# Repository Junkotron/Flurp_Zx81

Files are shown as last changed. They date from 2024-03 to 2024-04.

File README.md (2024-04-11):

# "Flurp zx81" on an fpga lots of stuff borrowed from "Blackice MX ZX81"
# Now for use on the Olimex ice40 8k board.

Second release some cleanup done but some elephants still remain

Features so far of the "Flurp"

* 16k or 1k ZX81 running at 3.2MHz
* PAL/NTSC output
* mic/ear/line for playing and recording sound files
* PS/2 keyboard connector (works with most USB keyboards)
* A debug port for a logic analyzer
* Serial port can now fairly reliably quick load programs
* 5 volt in from mobile charger, USB or similar

"Flurp" PCB drawings in kicad all in 0.1" grid so "banana finger" is no excuse
anymore, all hole-mounted like in the old days. If you, like me, fiddled
together a Zeddy at twelve you should be able to do this. Actually it is 
easier since no nerve-wrecking 40 pinners need be pressed in their sockets.
Components as far as I know can still be obtained, caps, connectors,
resistors and a single diode for over-voltage from the cassette interface
(could be omitted for the brave at heart).

First PCB is "in the air" as of this writing.

Since there is so many ideas of the connectors I made them as simple
pin and hole headers so there is no on-board fittings for RCA-jacks, 3.5mm
keyboard or similar since the chance of you obtaining whatever I got hold
of would be near-zero, just dive into that junkbox you got and see what
pops up!
I assume anyone attempting this should know their way around old-timer
connectors or if you are younger, wikipedia and google for info
on antiques :)

ZX81 currently only with 1k or 16k config, one major improvement with the
Olimex board is its 512k SRAM which we can use as we like.
Most other boards have SDRAM and although this probably also can
be made working I leave it as an excercise to the experts.
Currently only 16k is used. Plans to move the ROM here as well, this
currently resides in the internal FPGA memory.

As when mentioning the ROM I sucessfully replaced the original ROM with
the infamous "ASZMIC" rom image and got the example from the manual
working (see aszmic.sh in speedloader/) 

There is also an example of where the virtual keyboard produces a really
long 10 REM ... line suitable for storing machine code, in the old days
this would make your thumb go numb since this old piece of antique did not
have key repeat..

A composite output, there is an unfortunate "panache" with a wobble
on the first text line, dont know if this is due to the almost-PAL nature
of the ZX81 or something introduced later on. I tried a modulator (VHF) 
of some cheap no-brand type which would actually feed an older flatscreen
I got. Seems the really new flat screens cannot do PAL/NTSC anymore.
Not tried on a real fat-TV or monitor yet.

An "ear" input, changes from Sinclair original is some pulldown I seemed
to need on the FPGA side and some cowardly added zener 3.3 volts since
the FPGA is not 5v tolerant like the original ULA.

A "line" output, this is to be fed into a line input of some kind of PC 
soundblaster, I used the "aplay/arecord" utilities on Linux to act as the
tape recorder, it actually worked more or less out of the box.
I also added a modified bandbass filter for the line level that aims
as "doing the same thing" as the original "mic" circuitry but with a higher
level.

A PS/2 keyboard input with some resistors again to adapt to the
3.3 volt logic. It also works on most USB keyboards I tried, forcing them
into legacy PS/2 mode with some pullups.
If you take the usb connector, the wires in the schematic should align with
how the physical usb port is layed out so you can start with the plus which
use to be red and then work your way into whatever connector you have available
You could also get a PS/2 keyboard on ebay though this more obvious option
has not been tested.

The 34-pole connector for the FPGA module (Olimex) note that the notch in
the FPGA boards connector should face the nearest rim of the pcb, there is a 
"Notch!" silk screen marker. I'm not in any way a professional cad:er so
I may have broken some standard ways of working concerning the connectors.
Possibly you will use a female 0.1" headers with no notch. I found that
adding a small dot of hot glue, let it cool off some and then press the
module on will "mold" a notch without clogging the fpga board with glue.
This "notch" has been quite useful for avoiding gray smoke.

A "mic" output, this is made according to the originals but has as of yet
not worked. I added a 5 volt feed in case someone wants to try to make some
analog adaptions to it, I tried to amplify the signal with a 741 but to
no avail. Have not tested with a "real" tape recorder will do that when I
get a hold of one and some tape.

Some games require you to have only 1k so there is a connector that will
downgrade the Flurp to 1k after a reset, otherwise poking RAMTOP should
work for most such games.

Another connector will pull the "pin 22" on the "ULA" high which should
give you NTSC format, this is untested so far. In the old days most
american TV-sets would eat the PAL signal just as well.

Loading old games, I have been successful in using the "zx81putil" for
converting the p-file games available into wav files and then playing them
via the line-out of my PC sound blaster into the "ear" of the Flurp

.. Below here is some cool stuff that is not really necessary
.. these connectors can be omitted

A connector for a six-pin serial module which is popular with Arduinos
and similar. Now the speedloader is working and also you can "remote
type" on the ZX81 keyboard.

The olimex 32u4 or similar is used for programming the SPI flash of the
FPGA, we sometimes need to reset the FPGA, this can be done with the
reset button on the olimex ice40 board itself or with for instance
> sudo iceprogduino -t
Which reads the flash ID (but also does a full reset much faster than a full
 reprogram)

Speedloader can now both produce load files and fast load them
Check out "speedloader.txt" for more info

A way to run the ZX keyboard from this serial port is now implemented
the speeloader/keysend.c can be used to primitively execute commands
on the flurp, such as 'RUN' 'LOAD ""' 'NEW' etc.

A 10-pin connector for a Logic Probe, dirt cheap and really useful if you
want to dive into the FPGA firmware.

Thats all for now!

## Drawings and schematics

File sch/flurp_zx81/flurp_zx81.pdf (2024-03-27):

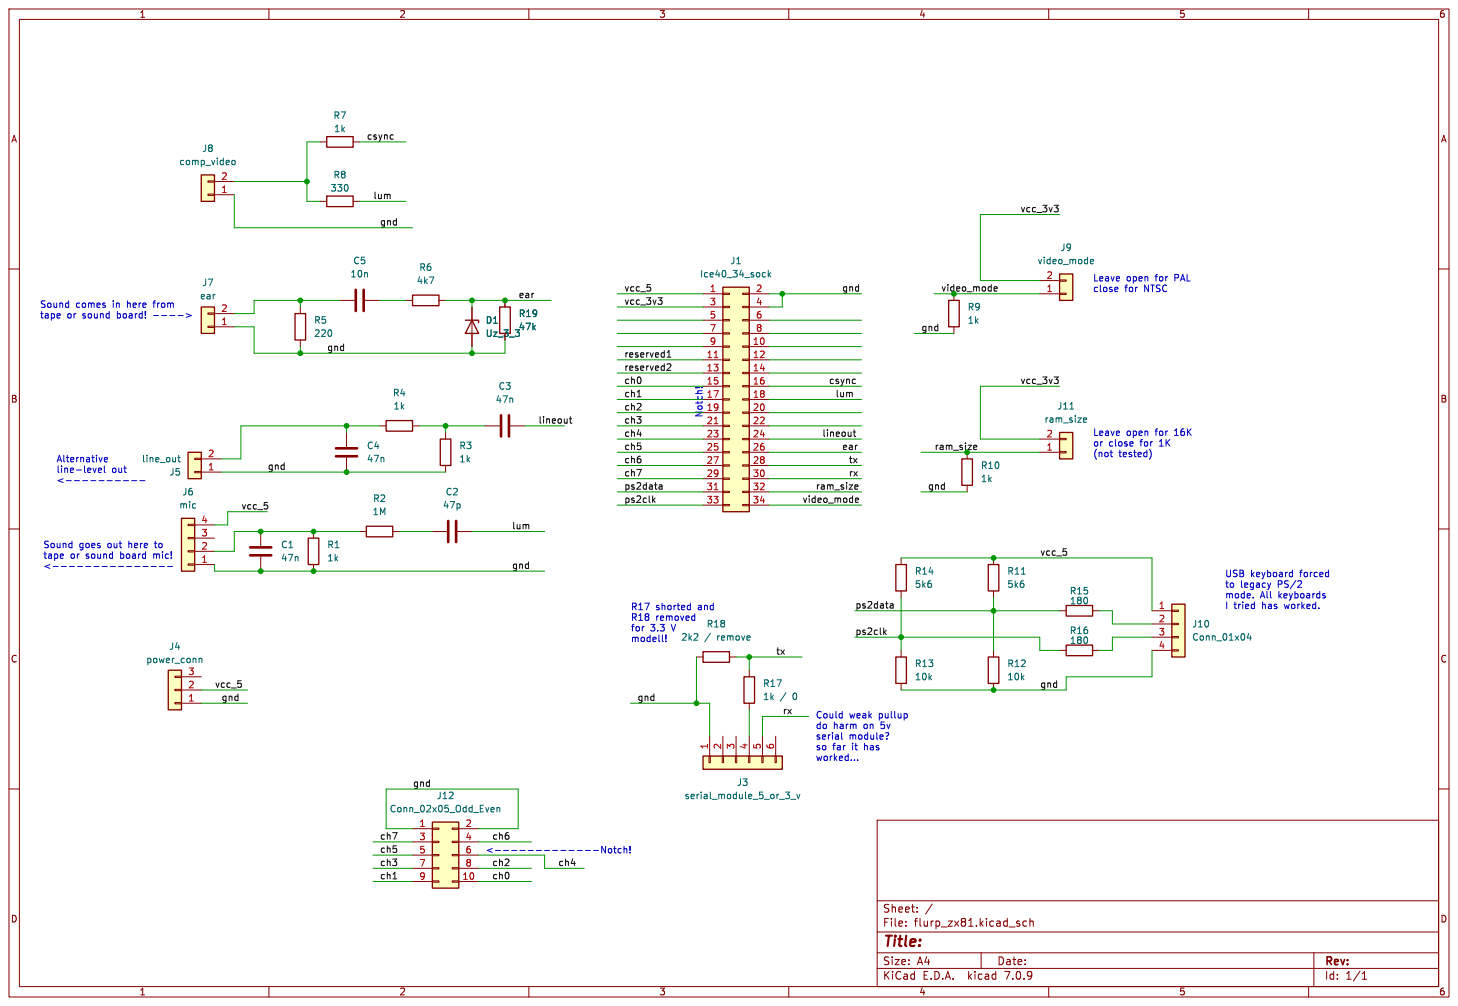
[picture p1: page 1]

Leave open for PAL
close for NTSC

tape or sound board mic! <--------------- Alternative

I tried has worked. Sound goes out here to

to legacy PS/2 mode. All keyboards

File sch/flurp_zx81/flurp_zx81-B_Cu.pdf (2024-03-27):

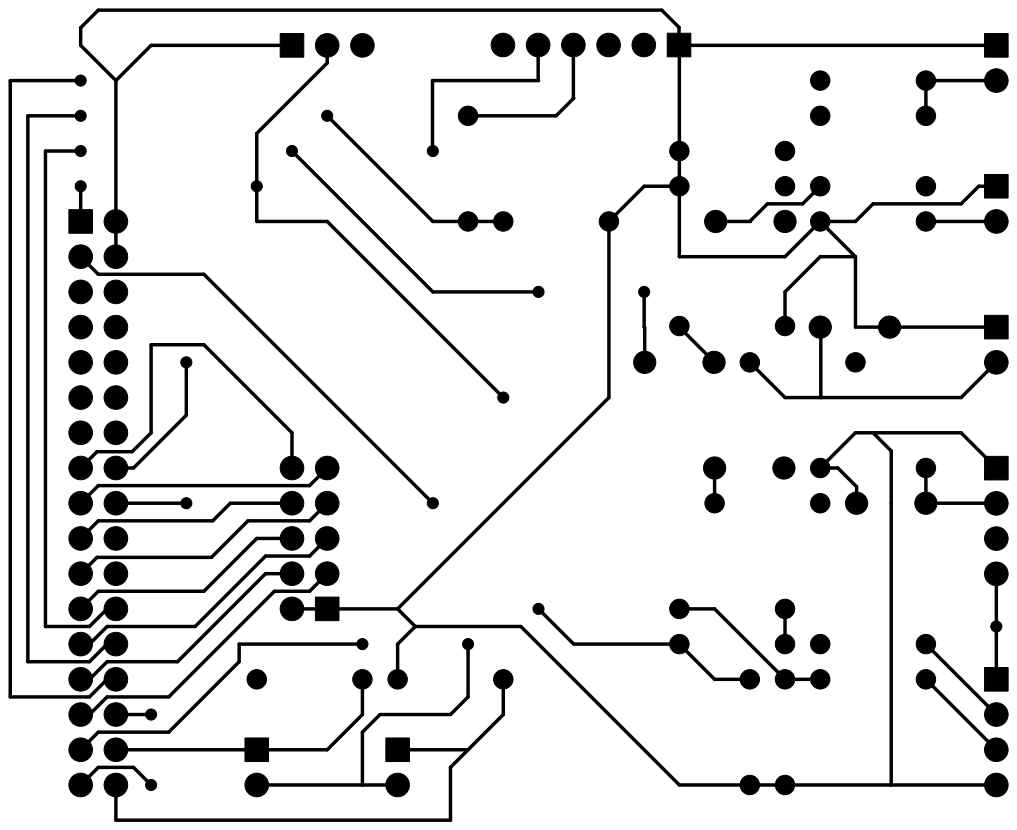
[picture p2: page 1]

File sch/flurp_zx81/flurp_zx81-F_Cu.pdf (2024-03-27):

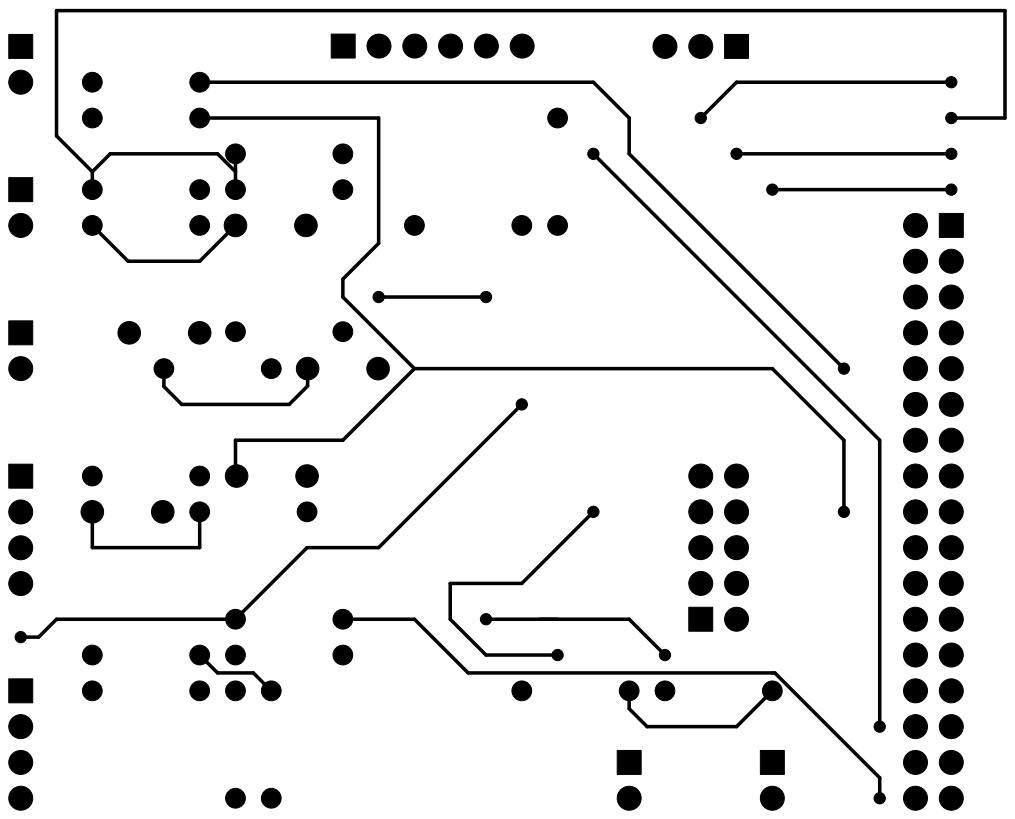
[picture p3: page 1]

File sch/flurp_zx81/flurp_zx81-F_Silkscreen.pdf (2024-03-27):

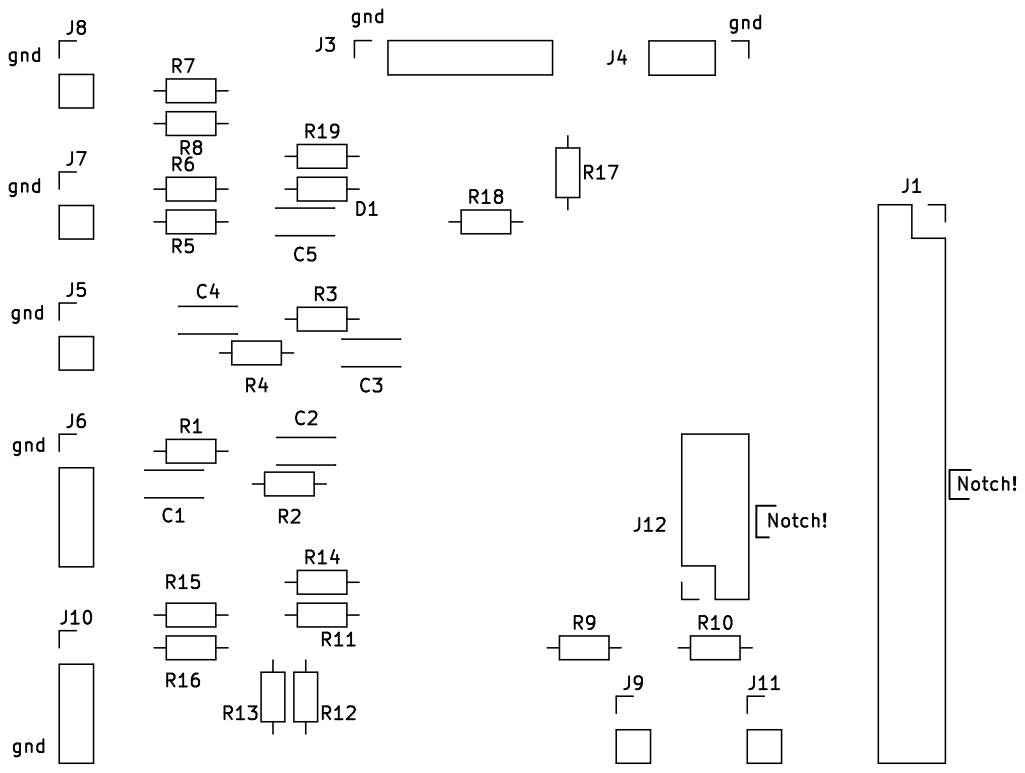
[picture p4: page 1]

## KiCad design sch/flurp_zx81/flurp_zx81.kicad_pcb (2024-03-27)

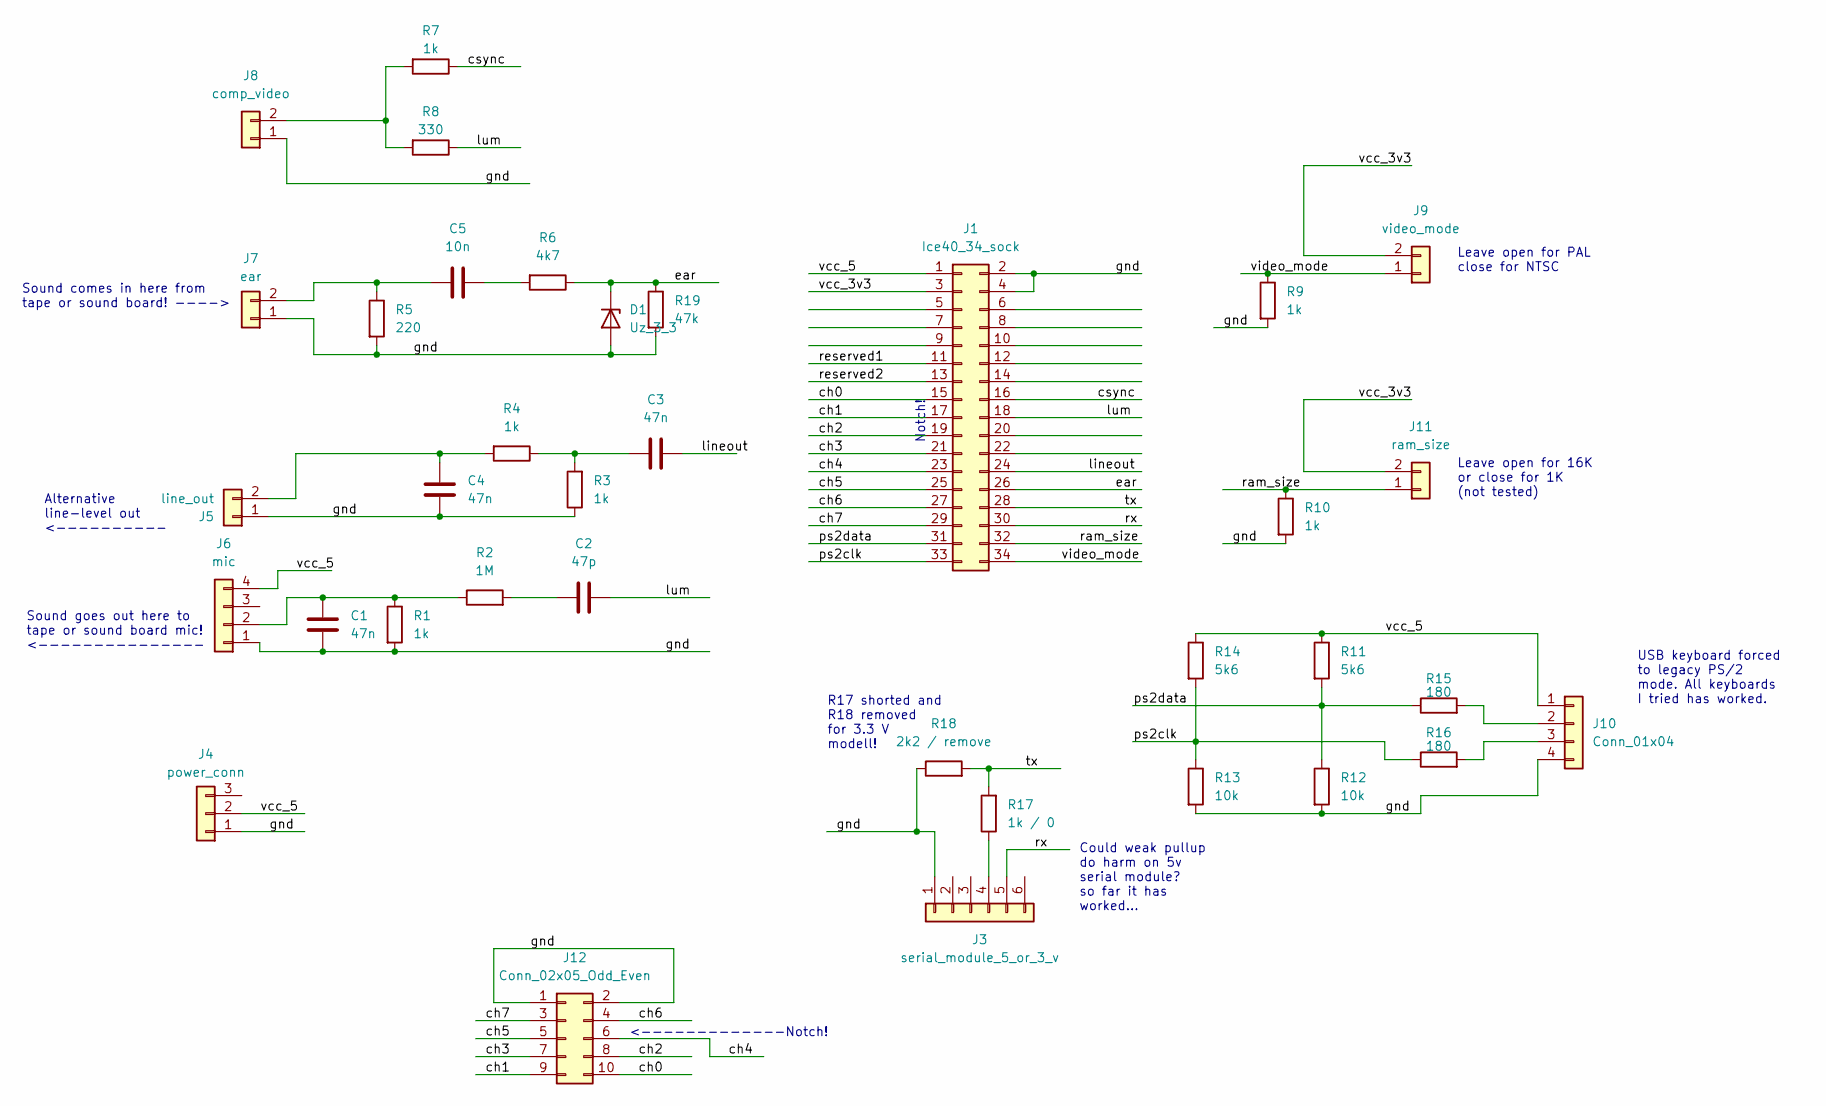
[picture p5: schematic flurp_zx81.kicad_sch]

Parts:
C1, C3, C4: 47n; C_Disc_D4.3mm_W1.9mm_P5.00mm
C2: 47p; C_Disc_D4.3mm_W1.9mm_P5.00mm
C5: 10n; C_Disc_D4.3mm_W1.9mm_P5.00mm
D1: Uz_3_3; R_Axial_DIN0204_L3.6mm_D1.6mm_P7.62mm_Horizontal
J1: Ice40_34_sock; PinSocket_2x17_P2.54mm_Vertical
J3: serial_module_5_or_3_v; PinSocket_1x06_P2.54mm_Vertical
J4: power_conn; PinHeader_1x03_P2.54mm_Vertical
J5: line_out; PinHeader_1x02_P2.54mm_Vertical
J6: mic; PinHeader_1x04_P2.54mm_Vertical
J7: ear; PinHeader_1x02_P2.54mm_Vertical
J8: comp_video; PinHeader_1x02_P2.54mm_Vertical
J9: video_mode; PinHeader_1x02_P2.54mm_Vertical
J10: Conn_01x04; PinHeader_1x04_P2.54mm_Vertical
J11: ram_size; PinHeader_1x02_P2.54mm_Vertical
J12: Conn_02x05_Odd_Even; PinSocket_2x05_P2.54mm_Vertical
R1, R3, R4, R7, R9, R10: 1k; R_Axial_DIN0204_L3.6mm_D1.6mm_P7.62mm_Horizontal
R2: 1M; R_Axial_DIN0204_L3.6mm_D1.6mm_P7.62mm_Horizontal
R5: 220; R_Axial_DIN0204_L3.6mm_D1.6mm_P7.62mm_Horizontal
R6: 4k7; R_Axial_DIN0204_L3.6mm_D1.6mm_P7.62mm_Horizontal
R8: 330; R_Axial_DIN0204_L3.6mm_D1.6mm_P7.62mm_Horizontal
R11, R14: 5k6; R_Axial_DIN0204_L3.6mm_D1.6mm_P7.62mm_Horizontal
R12, R13: 10k; R_Axial_DIN0204_L3.6mm_D1.6mm_P7.62mm_Horizontal
R15, R16: 180; R_Axial_DIN0204_L3.6mm_D1.6mm_P7.62mm_Horizontal
R17: 1k / 0; R_Axial_DIN0204_L3.6mm_D1.6mm_P7.62mm_Horizontal
R18: 2k2 / remove; R_Axial_DIN0204_L3.6mm_D1.6mm_P7.62mm_Horizontal
R19: 47k; R_Axial_DIN0204_L3.6mm_D1.6mm_P7.62mm_Horizontal

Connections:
/ch0: J1.15, J12.10
/ch1: J1.17, J12.9
/ch2: J1.19, J12.8
/ch3: J1.21, J12.7
/ch4: J1.23, J12.6
/ch5: J1.25, J12.5
/ch6: J1.27, J12.4
/ch7: J1.29, J12.3
/csync: J1.16, R7.1
/ear: D1.1 (K), J1.26, R6.1, R19.1
/gnd: C1.2, C4.1, D1.2 (A), J1.2, J1.4, J3.1, J4.1, J5.1, J6.1, J7.1, J8.1, J10.4, J12.1, J12.2, R1.2, R3.1, R5.2, R9.2, R10.2, R12.2, R13.2, R18.1, R19.2
/lineout: C3.2, J1.24
/lum: C2.2, J1.18, R8.1
/ps2clk: J1.33, R13.1, R14.2, R16.1
/ps2data: J1.31, R11.2, R12.1, R15.1
/ram_size: J1.32, J11.1, R10.1
/reserved1: J1.11
/reserved2: J1.13
/rx: J1.30, J3.5
/tx: J1.28, R17.2, R18.2
/vcc_3v3: J1.3, J9.2, J11.2
/vcc_5: J1.1, J4.2, J6.4, J10.1, R11.1, R14.1
/video_mode: J1.34, J9.1, R9.1
unnamed: C2.1, R2.2
unnamed: C3.1, R3.2, R4.1
unnamed: C5.2, R6.2
unnamed: J3.4, R17.1
unnamed: C4.2, J5.2, R4.2
unnamed: C1.1, J6.2, R1.1, R2.1
unnamed: C5.1, J7.2, R5.1
unnamed: J8.2, R7.2, R8.2
unnamed: J10.2, R15.2
unnamed: J10.3, R16.2

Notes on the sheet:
Sound goes out here to tape or sound board mic! <---------------
R17 shorted and R18 removed for 3.3 V modell!
Alternative line-level out <----------
<-------------Notch!
USB keyboard forced to legacy PS/2 mode. All keyboards I tried has worked.
Leave open for 16K or close for 1K (not tested)
Notch!
Could weak pullup do harm on 5v serial module? so far it has worked...
Leave open for PAL close for NTSC
Sound comes in here from tape or sound board! ---->

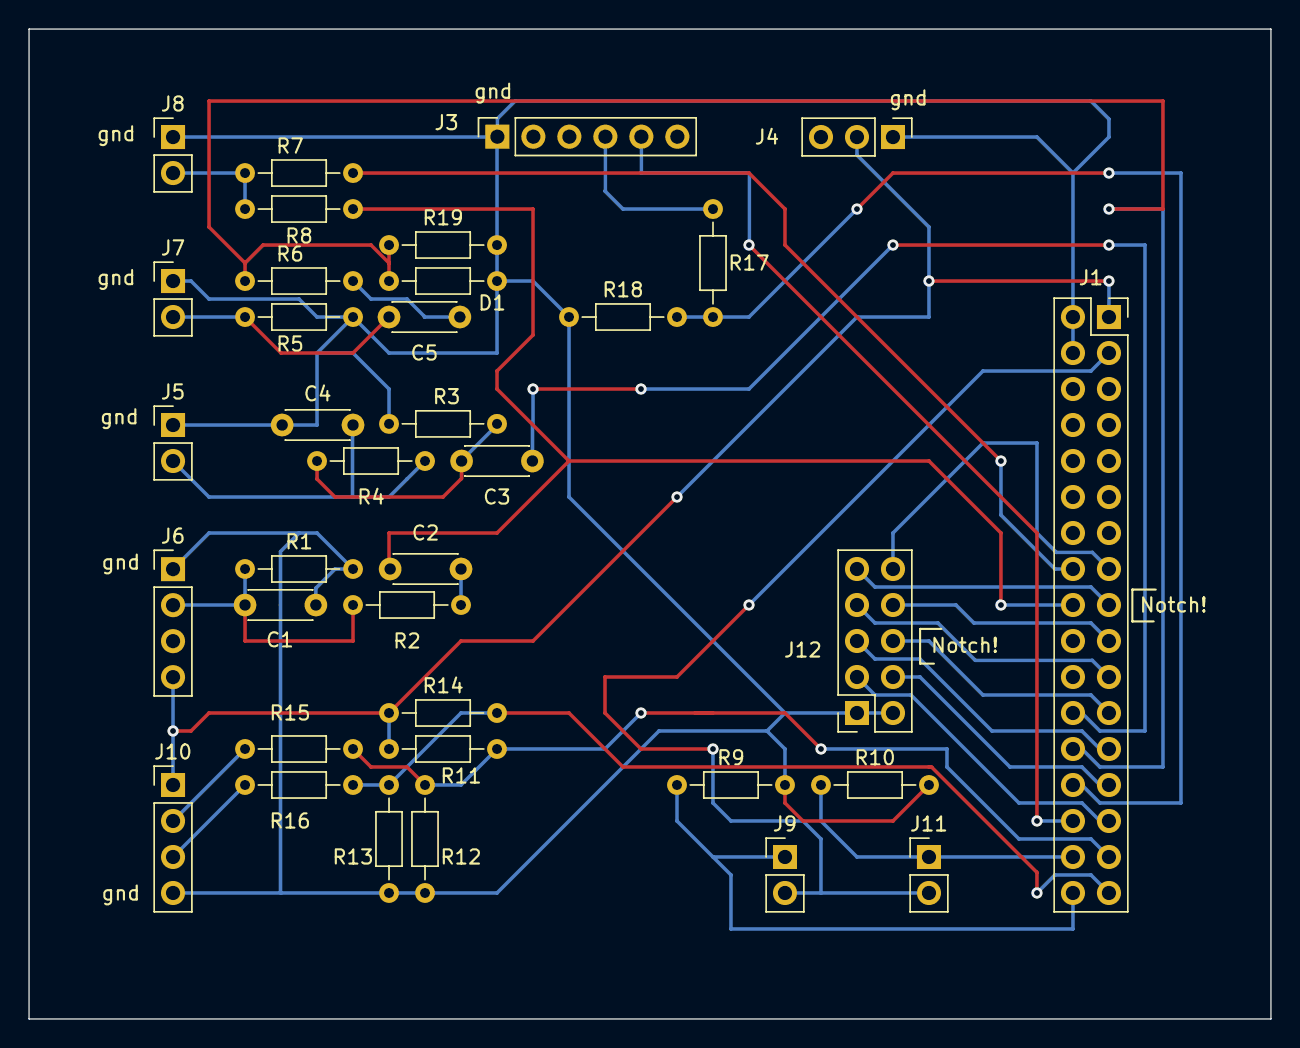
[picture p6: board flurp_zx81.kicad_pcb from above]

Board: 2 copper layers, 87.6 x 69.8 mm, 36 parts (0 on the bottom side), 31 nets.

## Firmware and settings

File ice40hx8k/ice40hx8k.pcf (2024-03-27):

# User Constraint File for BlackIcei Mx Acorn Atom (Ice40Atom)

# Onboard 25MHz oscillator
set_io clk_100mhz J3

set_io led1 M12
set_io led2 R16

set_io but1 K11
set_io but2 P13

# Physical config switches
set_io video_mode F3
set_io ram_size H3

# Keyboard - Matches Digilent PmodPS/2 
set_io ps2_clk           G3 #
set_io ps2_data          E2 # 

set_io csync J5
set_io lum H2

set_io ear F1

# This is actually "line out", mic shares with video pin zx original style
set_io mic H4

# VGA Output - Matches Digilent PmodVGA
#set_io red[3]           E4 # 
#set_io red[2]           R2 # 
#set_io red[1]           N5 #
#set_io red[0]           T2 # 

#set_io green[3]         B2 # 
#set_io green[2]         P5 # 
#set_io green[1]         R3 # 
#set_io green[0]         R5 # 

#set_io blue[3]          F5 # 
#set_io blue[2]          T3 # 
#set_io blue[1]          R4 # 
#set_io blue[0]          M7 # 

# ext 16k mem
set_io cs_n T6
set_io oe_n L9
set_io we_n T7


set_io a[0] N6
set_io a[1] T1
set_io a[2] P4
set_io a[3] R2
set_io a[4] N5
set_io a[5] T2
set_io a[6] P5
set_io a[7] R3
set_io a[8] R5
set_io a[9] T3
set_io a[10] R4
set_io a[11] M7
set_io a[12] N7
set_io a[13] P6
set_io a[14] M8
set_io a[15] T5
set_io a[16] R6
set_io a[17] P8

set_io d[0] T8
set_io d[1] P7
set_io d[2] N9
set_io d[3] T9
set_io d[4] M9
set_io d[5] R9
set_io d[6] K9
set_io d[7] P9


#set_io dbg_key[0] C2 # 
#set_io dbg_key[1] F4 # 
#set_io dbg_key[2] D2 # 
#set_io dbg_key[3] G5 # 
#set_io dbg_key[4] D1 # 
#set_io dbg_key[5] G4 # 
#set_io dbg_key[6] E3 # 
#set_io dbg_key[7] H5 # 

# salae port
# testch0 C2 # 
# testch1 F4 # 
# testch2 D2 # 
# testch3 G5 # 
# testch4 D1 # 
# testch5 G4 # 
# testch6 E3 # 
# testch7 H5 # 


# salae port
set_io testch[0] C2 # 
set_io testch[1] F4 # 
set_io testch[2] D2 # 
set_io testch[3] G5 # 
set_io testch[4] D1 # 
set_io testch[5] G4 # 
set_io testch[6] E3 # 
set_io testch[7] H5 # 

# Serial port monitor
set_io rx F2 # receives to serial adaptor
set_io tx H6 # sends from serial adaptor

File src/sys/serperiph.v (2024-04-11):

module serperiph

  (clock,
   reset,
   dce_rxd,
   dce_txd,

   busrq_n,
   busak_n,

   ri,
   ri_ce_n,
   ri_oe_n,
   ri_we_n,
   ri_addr,
   ri_data,
   ext_ram_out,

   // TODO: remove not used?
   cpu_addr,

   // Break bank switch stuff
   break_addr,
   break_flag,
   
   // Reset of CPU from serial line
   do_reset,
   
   // Keyboard remote
   kb_strobe,
   press,
   row,
   col,

   testch
      
   );
  `include "parameters.vh"
   input clock;
   input reset;

   input dce_rxd;
   output reg dce_txd;   
   
   wire [7:0] receive_data;
   wire 	    recv_strobe;
   wire [7:0] send_data;
   wire 	    send_strobe;
   wire 	    data_avail;

   wire 	    read_strobe;

   wire 	    read_cycle;
   
   output reg 	    busrq_n;
   input wire 	    busak_n;

   // Filtered send_strobe only active when data is incoming
   // (as opposed to command, address and length)
   wire 		    write_strobe;
   wire [7:0] 	    write_data;
   wire [7:0] 	    reg_addr;

   reg 		    oldwstr;
   reg 		    oldrstr;
   // Write machine
   // Here we gather all write signals
   // to simplify writing comms driver in other end
   // Needs shadow registers where applicable

   // Packets: <cmd> <addr> <size n> <b1> <b2> ... <bn>
   // 02 00 01 00  02 00 01 02 - will set busrq_n (and others) low and will set ri high
   
   // 02 00 01 00  02 00 01 01 - will set ri low and will set busrq_n high and others low
   
   // The 00082h test "10 REM BRANDT" - a7,b7 is inverter B,R in zx code
   // 02 01 01 00   02 02 01 00   02 03 01 82   02 04 02 a7 b7
   reg [17:0] 	    addrtmp;

   // This is how to do readback of 82 and 83
   // 02 01 01 00   02 02 01 00   02 03 01 82   01 01 02
   
   // Read machine
   // Here we have all read registers for easy reference
   reg [7:0] datar0, datar1, datar2, datar3;

   reg 	     avail1;
   
   
   reg 	     wtrig, rtrig;

   reg 	     newaddr;

   reg [7:0]	     echoreg;
   
   always @(posedge clock)
     begin
	if (reset == 1)
	  begin
	     // Internal
	     oldwstr = 0;
	     oldrstr = 0;
	     wtrig=0;
	     rtrig=0;
	     newaddr=0;
	     echoreg=0;

	     // "real" signals, these values are also
	     // to be set by shadow register!
	     // TODO: some common "Include" with this between
	     // here and C-code?
	     busrq_n=1;
	     ri=0;
	     break_flag=0;


	     // Remote keyboard
	     kb_strobe=0;
 	     press=0;
	     row=3'b111;
	     col=3'b111;

	  end

	if (wtrig==0 && read_cycle==0)
	  begin

	     // We need to trig on neg since the data and strobe
	     // are altered at the same time so we avoid glitches
	     if (write_strobe == 0 && oldwstr==1)
	       
	       case (reg_addr)
		 8'h00: 
		   begin
		      // Single bit:ers gather here..
		      busrq_n=write_data[0] ;
		      // This activates the ram inject as such,
		      // wait for busak before activating this!!
		      ri = write_data[1];
		      break_flag = write_data[2];
		      
		      // ...
		   end
		 // Three bytes to set RAM address for bus injection
		 8'h01: 
		   begin
		      newaddr=1;
		      addrtmp[17:16]=write_data[1:0];
		   end
		 8'h02: 
		   begin 
		      newaddr=1;
		      addrtmp[15:8]=write_data;
		   end
		 8'h03: 
		   begin
		      newaddr=1;
		      addrtmp[7:0]=write_data;
		   end

		 // Writing data apart from setting ri_data it also
		 // trigger a set of events that should be finished
		 // well before another serial byte arrives
		 8'h04:
		   begin
		      ri_addr = addrtmp;
		      addrtmp = addrtmp + 1;
		      ri_data = write_data;
		      wtrig = 1;
		   end

		 8'h05:
		   echoreg = write_data + 1;

		 8'h06:
		   break_addr[15:8] = write_data;

		 8'h07:
		   break_addr[7:0] = write_data;

		 8'h08:
		   begin
		      kb_strobe=write_data[7];
 		      press=write_data[6];
		      row=write_data[5:3];
		      col=write_data[2:0];
		   end
	       endcase
	     
	     oldwstr = write_strobe;
	  end
	else
	  begin
	     if (write_strobe == 1) wtrig = 0;
	  end

	if (read_cycle==0)
	  rtrig=0;
	
	if (read_cycle==1)
	  begin
	     if (rtrig == 0)
	       begin
		  case (reg_addr)
		    8'h00:
		      datar0 = { busak_n, 7'b0000000 };
		    8'h01:
		      begin 
			 // This is a consequetive reader register

			 // TODO: fix why is this???
			 if (newaddr) addrtmp = addrtmp - 1;
			 newaddr = 0;
			 ri_addr=addrtmp;
			 addrtmp = addrtmp + 1;
			 rtrig = 1;
		      end
		    8'h02: // echo reg + 1 of write (05)
		      datar2 = echoreg;
		    8'h03:
		      datar3 = 8'hba;
		  endcase // case (reg_addr)
		  // TODO REMEMBER to add bits here and there if we need more
		  // than 4 read regs for now... could we make the mux all here
		  // instead?
	       end
	     else
	       begin
		  if (read_strobe == 1 && oldrstr==0) rtrig = 0;
	       end // else: !if(rtrig == 0)
	     oldrstr = read_strobe;
	  end // if (read_cycle==1)
     end

   
   // Connectors for memory manipulation
   output reg 	    ri;
   output reg 	    ri_ce_n=1;
   output reg 	    ri_oe_n=1;
   output reg 	    ri_we_n=1;
   output reg [17:0] ri_addr=0;
   output reg [7:0]      ri_data=0;
   input wire [7:0] 	 ext_ram_out;
   

   // TODO: reader and writer is never on at the same time
   // so they could probably share a lot of this
   //
   // Ram writer machine, goes a turn when data is written
   // possibly repeatedly
   reg 			 old_wtrig;
   reg [2:0] 		 ri_wstate;

   reg [6:0] 		 wpausecnt;

   reg [7:0] 		 readmemdata;

   // Ram reader machine, goes a turn when data is read
   // possibly repeatedly
   reg 			 old_rtrig;
   reg [2:0] 		 ri_rstate;

   reg [6:0] 		 rpausecnt;

   
   always @(posedge clock)
     begin
	if (reset == 1)
	  begin
	     old_wtrig=0;
	     ri_wstate=3'b000;
	     wpausecnt = 0;
	     old_rtrig=0;
	     ri_rstate=3'b000;
	     rpausecnt = 0;
	  end
	if (wpausecnt!=0)
	  begin
	     wpausecnt = wpausecnt - 1;
	  end
	else
	  begin
	     case (ri_wstate)
	       3'b000:
		 begin
		    if (old_wtrig == 0 && wtrig == 1)
		      begin
			 ri_wstate=ri_wstate+1;
			 wpausecnt=100;
		      end
		    old_wtrig = wtrig;
		 end
	       3'b001:
		 begin
		    ri_we_n = 0;
		    ri_wstate=ri_wstate+1;
		    wpausecnt=100;
		 end
	       3'b010:
		 begin
		    ri_ce_n = 0;
		    ri_wstate=ri_wstate+1;
		    wpausecnt=100;
		 end
	       3'b011:
		 begin
		    ri_ce_n = 1;
		    ri_wstate=ri_wstate+1;
		    wpausecnt=100;
		 end
	       3'b100:
		 begin
		    ri_we_n = 1;
		    ri_wstate=0;
		 end
	     endcase
	  end
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

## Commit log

2024-03-27 initial add of what i think is all
    [flurp_zx81.kicad_pcb, flurp_zx81.kicad_sch]
2024-03-27 wrong placed files
    [flurp_zx81.kicad_pcb, flurp_zx81.kicad_sch]
2024-03-27 added leg conf
